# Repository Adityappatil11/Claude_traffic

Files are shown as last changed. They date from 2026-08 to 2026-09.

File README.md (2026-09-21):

# Claude Code Hardware Traffic Light Indicator 🚥

A physical status indicator with LED states and audio buzzer alerts for [Claude Code](https://docs.anthropic.com/claude/docs/claude-code) and CLI coding agents powered by an ESP8266 / NodeMCU.

---

## 🌟 Visual & Audio Signals

| State | LED Color | Buzzer Pattern | Trigger |
| :--- | :--- | :--- | :--- |
| **Prompt Dispatched / Action Needed** | 🟡 Yellow | 3 Short Beeps (120ms each) | `UserPromptSubmit`, `PermissionRequest`, `Notification` |
| **Tool Execution** | 🔵 Blue | Silent | `PreToolUse`, `PostToolUse` (Edit, Bash, Read) |
| **Prompt Completed** | ⚫ Off | 2 Short Beeps (120ms each) | `Stop`, `SessionEnd` |
| **Idle / Manual Off** | ⚫ Off | Silent | Manual `off` command |
| **Context Limit / Out of Tokens** | 🔴 Red | 1 Long Alarm (800ms) | Context window $\ge 95\%$ or `stop_reason == "max_tokens"` |

---

## 🛠️ Hardware Wiring

| Component | NodeMCU Pin | GPIO Pin | Notes |
| :--- | :--- | :--- | :--- |
| **🔴 Red LED** | `D1` | GPIO 5 | 220Ω–330Ω to Anode (+), Cathode to GND |
| **🟡 Yellow LED** | `D2` | GPIO 4 | 220Ω–330Ω to Anode (+), Cathode to GND |
| **🔵 Blue LED** | `D5` | GPIO 14 | 220Ω–330Ω to Anode (+), Cathode to GND |
| **🔔 Buzzer** | `D6` | GPIO 12 | Positive (+) to D6, Negative (-) to GND |

---

## 🚀 Quick Start

### 1. Prerequisites & Toolchain Setup

Install `arduino-cli`, `esptool`, and the ESP8266 board core:

```bash
# Install arduino-cli
curl -fsSL [https://raw.githubusercontent.com/arduino/arduino-cli/master/install.sh](https://raw.githubusercontent.com/arduino/arduino-cli/master/install.sh) | BINDIR=~/.local/bin sh
export PATH=$PATH:~/.local/bin

# Initialize config & add ESP8266 core
arduino-cli config init
arduino-cli config add board_manager.additional_urls [http://arduino.esp8266.com/stable/package_esp8266com_index.json](http://arduino.esp8266.com/stable/package_esp8266com_index.json)
arduino-cli core update-index
arduino-cli core install esp8266:esp8266

# Install esptool & serial tools
pip install esptool pyserial

```

---

### 2. Identify the Port & Fix Permissions

Plug your NodeMCU board into your computer and find the active serial port:

#### Linux

```bash
# Confirm that the NodeMCU is available as /dev/ttyUSB0
sudo ls -l /dev/ttyUSB* /dev/ttyACM* 2>/dev/null

# Give the current machine session access to the board
sudo chmod 666 /dev/ttyUSB0

# Or view kernel hardware detection logs
dmesg | grep -i tty
```

> **Important Linux Fixes:**
> 1. **Permission Denied:** The `chmod` command above is temporary and may need to be repeated after reconnecting or restarting the board. For permanent access, add your user to `dialout`, then log out and back in:
> ```bash
> sudo usermod -a -G dialout $USER
> ```
> 
> 
> 2. **Device Auto-Disconnecting (`brltty` Conflict):** If `/dev/ttyUSB0` disappears immediately after plugging in:
> ```bash
> sudo apt remove --purge -y brltty
> 
> ```
> 
> 
> 
> 

#### Windows (PowerShell)

```powershell
# List available COM ports
Get-CimInstance Win32_SerialPort | Select-Object DeviceID, Description

```

*(Look for `Silicon Labs CP210x` or `USB-SERIAL CH340` $\rightarrow$ e.g., `COM3`).*

---

### 3. Configure, Compile & Flash the Firmware

1. Open `firmware/firmware.ino` and enter the two 2.4 GHz Wi-Fi profiles:
```cpp
WifiCredential wifiCredentials[] = {
  {"Vishwa", "YOUR_PASSWORD", IPAddress(192, 168, 0, 200), IPAddress(192, 168, 0, 1)},
  {"Gramle_Jio", "YOUR_PASSWORD", IPAddress(192, 168, 31, 200), IPAddress(192, 168, 31, 1)}
};

```

The ESP8266 tries the profiles in order. It uses `192.168.0.200` on Vishwa and `192.168.31.200` on Gramle_Jio.

2. From the project directory, compile the binary:
```bash
arduino-cli compile --fqbn esp8266:esp8266:nodemcuv2 --output-dir ./build firmware/
```

3. Confirm the board is connected and make the serial port accessible:

```bash
sudo ls -l /dev/ttyUSB* /dev/ttyACM* 2>/dev/null
sudo chmod 666 /dev/ttyUSB0
```

4. Flash the ESP8266 using the settings verified with this board:

```bash
python3 -m esptool --chip esp8266 --port /dev/ttyUSB0 --baud 57600 --no-stub write-flash 0x0 ./build/firmware.ino.bin
```

A successful flash ends with `Verifying written data...` followed by `Hard resetting via RTS pin...`.

5. If esptool cannot connect automatically, put the board into **Bootloader Mode** and run the flash command again:

* Press and hold the physical **`FLASH`** (or `BOOT`) button.
* Tap the physical **`RST`** button once.
* Release the **`FLASH`** button.

#### Windows flashing

```bash
# Windows (replace COM3 with your port)
python -m esptool --port COM3 --baud 115200 --no-stub --before no-reset --after no-reset write-flash 0x0 ./build/firmware.ino.bin
```

---

### 4. Monitor Serial Output

1. **Press the `RST` button** on your NodeMCU once to start the firmware.
2. Open the serial monitor:
```bash
# Linux / macOS
python3 -m serial.tools.miniterm /dev/ttyUSB0 115200

# Windows
python -m serial.tools.miniterm COM3 115200

```

3. Watch the terminal for your Wi-Fi confirmation:
```text
WiFi Connected!
Connected SSID: Vishwa
NodeMCU Fixed IP Address: 192.168.0.200

```

4. Press `Ctrl + ]` to exit the monitor.

---

### 5. Configure the Light Sender and Hooks

`hw_light.py` sends every light command to both saved ESP8266 addresses. No per-PC IP edit is needed.

| Wi-Fi | ESP8266 address |
| :--- | :--- |
| Vishwa | `192.168.0.200` |
| Gramle_Jio | `192.168.31.200` |

The computer only needs to be connected to either Wi-Fi network.

#### Linux

```bash
chmod +x /path/to/Claude_traffic/hw_light.py

# Claude Code: only copies when no settings file exists
mkdir -p ~/.claude
test -e ~/.claude/settings.json || cp settings.json.example ~/.claude/settings.json

# Codex: only copies when no hooks file exists
mkdir -p ~/.codex
test -e ~/.codex/hooks.json || cp codex-hooks.json.example ~/.codex/hooks.json
```

Replace `/media/aditya/STUDY/projects/Claude_traffic` in the example JSON if your project is in a different folder. Use `.claude/settings.json` or `.codex/hooks.json` in a repository instead when hooks should only apply to that repository. Restart Claude Code or Codex after changing its settings.

#### Windows (PowerShell)

1. Install Python 3 and check that the launcher works:

```powershell
py -3 --version
```

2. Copy this project to a stable path, such as `C:\Users\YOUR_NAME\Claude_traffic`.

3. Replace every `YOUR_NAME` in [settings.windows.json.example](settings.windows.json.example), then merge it into:

```text
C:\Users\YOUR_NAME\.claude\settings.json
```

4. Replace every `YOUR_NAME` in [codex-hooks.windows.json.example](codex-hooks.windows.json.example), then copy it to:

```text
C:\Users\YOUR_NAME\.codex\hooks.json
```

Restart Claude Code or Codex after saving. Codex may ask you to trust the hook the first time it runs.

---

### 6. Manual Testing

These tests do not require Claude Code or Codex. They send the same UDP commands that the hooks send.

### Claude Desktop on Windows (experimental)

Claude Desktop does not expose Claude Code lifecycle hooks. The included log
watcher can infer activity from local Desktop logs, but log wording can change
between Claude releases.

```powershell
# Show the Claude Desktop logs detected on this PC
py -3 .\claude_desktop_watcher.py --discover

# First test without sending anything to the hardware. Send a Claude message
# while this is running and inspect the detected colour events/log wording.
py -3 .\claude_desktop_watcher.py --dry-run --verbose

# Run the traffic-light watcher
py -3 .\claude_desktop_watcher.py
```

The watcher checks both the classic `%APPDATA%\Claude\logs` location and the
Microsoft Store/MSIX package location. If automatic discovery misses the active
log, pass it explicitly with `--log-file "C:\path\to\claude.ai-web.log"`.

#### Linux

Run these from the project directory:

```bash
# Yellow: prompt / attention needed
python3 hw_light.py UserPromptSubmit

# Blue: tool running
python3 hw_light.py PreToolUse

# Red: interrupt / context warning
python3 hw_light.py Interrupt

# Complete: LEDs off with two short beeps
python3 hw_light.py Stop

# Guided sequence: Yellow -> Blue -> Off, plus manual colour selection
python3 simulate_claude.py
```

#### Windows (PowerShell)

Open PowerShell in the project directory:

```powershell
# Yellow: prompt / attention needed
py -3 .\hw_light.py UserPromptSubmit

# Blue: tool running
py -3 .\hw_light.py PreToolUse

# Red: interrupt / context warning
py -3 .\hw_light.py Interrupt

# Complete: LEDs off with two short beeps
py -3 .\hw_light.py Stop

# Guided sequence: Yellow -> Blue -> Off, plus manual colour selection
py -3 .\simulate_claude.py
```

If the light does not change, confirm the PC is connected to the same Wi-Fi as the board, then ping the active address:

```bash
# Linux: use 192.168.31.200 when connected to Gramle_Jio
ping -c 1 192.168.0.200
```

```powershell
# Windows: use 192.168.31.200 when connected to Gramle_Jio
ping 192.168.0.200
```

---

### 7. Claude Desktop Setup (Manual MCP Light Controls)

Claude Desktop does not provide Claude Code lifecycle hooks. Instead, this project includes a local MCP server that gives Claude Desktop tools to control the light on request:

| Tool | Action |
| :--- | :--- |
| `light_test` | Sends yellow as a quick connectivity test |
| `light_yellow` | Turns on yellow |
| `light_blue` | Turns on blue |
| `light_red` | Turns on red |
| `light_off` | Turns all LEDs off |
| `set_light` | Accepts `yellow`, `blue`, `red`, or `off` |

You do **not** need an `.mcpb` file for this manual setup. The `.mcpb` file is only needed when using Claude Desktop's **Settings -> Extensions -> Advanced settings -> Install Extension...** flow.

The MCP server sends every command to both ESP8266 addresses:

```text
192.168.0.200
192.168.31.200
```

That means the same Claude Desktop config can work whether the computer is connected to the Vishwa Wi-Fi or the Gramle_Jio Wi-Fi.

#### Windows

1. Open PowerShell and go to the project directory:

```powershell
cd C:\Users\graml\Downloads\Claude_traffic
```

If you keep the project somewhere else, use that folder instead.

2. Install the MCP dependency:

```powershell
py -3 -m pip install -r .\claude_desktop\requirements.txt
```

3. Confirm the MCP server can start:

```powershell
py -3 .\claude_desktop\traffic_light_mcp.py
```

The command may wait silently because Claude Desktop normally talks to it over standard input/output. Press `Ctrl+C` to stop it after confirming there is no startup error.

4. Open the Claude Desktop config file:

```powershell
notepad "$env:APPDATA\Claude\claude_desktop_config.json"
```

If the file does not exist, create it.

5. Add or merge this config. If the file already has other MCP servers, only add the `esp8266-traffic-light` entry inside `mcpServers`.

```json
{
  "mcpServers": {
    "esp8266-traffic-light": {
      "command": "py",
      "args": [
        "-3",
        "C:\\Users\\graml\\Downloads\\Claude_traffic\\claude_desktop\\traffic_light_mcp.py"
      ],
      "env": {
        "ESP8266_LIGHT_IPS": "192.168.0.200,192.168.31.200"
      }
    }
  }
}
```

6. Fully quit Claude Desktop and reopen it.

7. Start a chat and ask:

```text
Use the esp8266 traffic light tool and run light_test.
```

The yellow light should turn on. Claude Desktop may ask you to approve the tool the first time.

#### macOS

1. Copy the project to your Mac and install the MCP dependency:

```bash
cd /Users/YOUR_NAME/Claude_traffic
python3 -m pip install -r claude_desktop/requirements.txt
```

2. Open or create Claude Desktop's config file:

```bash
open "$HOME/Library/Application Support/Claude/claude_desktop_config.json"
```

If `open` does not create the file, make the folder and file manually:

```bash
mkdir -p "$HOME/Library/Application Support/Claude"
touch "$HOME/Library/Application Support/Claude/claude_desktop_config.json"
```

3. Add or merge this config. Replace `YOUR_NAME` with your macOS user name:

```json
{
  "mcpServers": {
    "esp8266-traffic-light": {
      "command": "python3",
      "args": [
        "/Users/YOUR_NAME/Claude_traffic/claude_desktop/traffic_light_mcp.py"
      ],
      "env": {
        "ESP8266_LIGHT_IPS": "192.168.0.200,192.168.31.200"
      }
    }
  }
}
```

4. Fully quit Claude Desktop and reopen it.

5. In a chat, ask:

```text
Use the esp8266 traffic light tool and run light_test.
```

#### Linux Testing

Claude Desktop support on Linux depends on the installation channel/version. You can still test the MCP server itself from this repository:

```bash
cd /media/aditya/STUDY/projects/Claude_traffic
python3 -m pip install -r claude_desktop/requirements.txt
python3 claude_desktop/traffic_light_mcp.py
```

Press `Ctrl+C` after confirming the server starts.

Use this config shape if your Claude Desktop build exposes a local MCP config file:

```json
{
  "mcpServers": {
    "esp8266-traffic-light": {
      "command": "python3",
      "args": [
        "/media/aditya/STUDY/projects/Claude_traffic/claude_desktop/traffic_light_mcp.py"
      ],
      "env": {
        "ESP8266_LIGHT_IPS": "192.168.0.200,192.168.31.200"
      }
    }
  }
}
```

The ready-made examples are also included here:

| Platform | Example file |
| :--- | :--- |
| macOS | [claude_desktop_config.macos.example.json](claude_desktop/claude_desktop_config.macos.example.json) |
| Windows | [claude_desktop_config.windows.example.json](claude_desktop/claude_desktop_config.windows.example.json) |

#### Troubleshooting

If Claude Desktop does not show the tool, check these first:

1. Restart Claude Desktop after changing `claude_desktop_config.json`.
2. Confirm Python works from the same terminal: `py -3 --version` on Windows or `python3 --version` on macOS/Linux.
3. Confirm the MCP package is installed: `py -3 -m pip show mcp` or `python3 -m pip show mcp`.
4. Confirm the path in `args` points to the real `traffic_light_mcp.py` location.
5. Confirm the ESP8266 is on either `192.168.0.200` or `192.168.31.200`.

For automatic Claude Desktop activity detection on Windows, you can also try the experimental log watcher:

```powershell
py -3 .\claude_desktop_watcher.py --discover
py -3 .\claude_desktop_watcher.py --dry-run --verbose
py -3 .\claude_desktop_watcher.py
```

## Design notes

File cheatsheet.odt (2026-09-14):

Here is a complete, structured breakdown of every issue we encountered, why it happened, and the exact Linux CLI commands that solved it.

### Phase 1: Fixing Linux Hardware & Driver Conflicts

#### 1. The brltty Conflict (Device Disconnecting Immediately)

- What happened: Ubuntu and Debian install brltty (Braille Display Daemon) by default. When a CH340 USB-to-Serial converter is plugged in, brltty misidentifies it as a Braille teletype and claims the USB interface, forcibly disconnecting /dev/ttyUSB0 half a second later.
- The fix:
  Bash
  # Completely remove the conflicting braille daemon
  sudo apt remove --purge -y brltty
  sudo systemctl stop brltty-udev.service 2>/dev/null
  sudo systemctl mask brltty-udev.service 2>/dev/null

#### 2. Serial Port Permissions (Permission denied / dialout)

- What happened: Linux restricts raw access to hardware serial ports (/dev/ttyUSB*, /dev/ttyACM*) to the root user and the dialout group. Standard user accounts cannot write to serial ports without being in this group.
- The fix:
  Bash
  # Add your current user to the dialout group
  sudo usermod -a -G dialout $USER
  # Make the active device read/write accessible to all local users
  sudo chmod 666 /dev/ttyUSB0

### Phase 2: Headless Toolchain Setup (arduino-cli)

Instead of relying on heavy desktop IDEs, arduino-cli allows compiling and managing board cores completely from the terminal.

Bash

# 1. Download and install arduino-cli binary to your local user bin

curl -fsSL https://raw.githubusercontent.com/arduino/arduino-cli/master/install.sh | BINDIR=~/.local/bin sh

export PATH=$PATH:~/.local/bin

# 2. Register ESP8266 board manager repository index

arduino-cli config init

arduino-cli config add board_manager.additional_urls http://arduino.esp8266.com/stable/package_esp8266com_index.json

# 3. Update the package index and install the core toolchain (xtensa-lx106 compiler, SDK, libraries)

arduino-cli core update-index

arduino-cli core install esp8266:esp8266

### Phase 3: Headless Compilation to Raw Binary

Compiling with --output-dir produces a self-contained .bin firmware file that can be flashed using any low-level tool:

Bash

# Compiles the sketch targeting NodeMCU 1.0 (ESP-12E) and outputs to ./build/

arduino-cli compile --fqbn esp8266:esp8266:nodemcuv2 --output-dir ./build firmware/

- --fqbn stands for Fully Qualified Board Name (esp8266:esp8266:nodemcuv2).
- Generates ./build/firmware.ino.bin.

### Phase 4: Solving the [Errno 5] / [Errno 71] Flashing Crashes

#### Why esptool.py Failed Initially:

1. The Stub Mismatch: By default, esptool uploads a small RAM program (a "stub flasher") into the ESP8266's memory to flash at higher baud rates. On cheap CH340 clones running under the Linux kernel's ch341 driver, the USB packet framing breaks during this stub handoff, causing [Errno 71] Protocol error.
2. DTR/RTS Line Crash: The automatic reset circuitry pulses the DTR and RTS lines. On some USB controllers, this line transition resets the USB endpoint mid-transfer, dropping the port and causing [Errno 5] Input/output error.

#### The Solution: ROM Bootloader + Manual Sync

1. Manual Bootloader Entry: Holding FLASH, tapping RST, and releasing FLASH puts the ESP8266 chip directly into its internal ROM bootloader state in hardware.
2. Direct Flashing Command:
  Bash
  python3 -m esptool --port /dev/ttyUSB0 --baud 115200 --no-stub --before no-reset --after no-reset write-flash 0x0 ./build/firmware.ino.bin
  - --no-stub: Bypasses the RAM flasher stub completely and speaks directly to the built-in ESP8266 ROM flasher.
  - --before no-reset: Tells esptool NOT to send DTR/RTS serial pulses before flashing (preventing USB controller resets).
  - --after no-reset: Prevents esptool from sending a hardware line reset after writing (preventing pySerial I/O crashes).
  - 0x0: Flashes the binary directly to the primary boot address of the ESP8266 SPI flash memory.

### Phase 5: Monitoring Output

Bash

# Built-in lightweight terminal monitor via pySerial

python3 -m serial.tools.miniterm /dev/ttyUSB0 115200

- Quit: Ctrl + ]

### Quick Cheat Sheet for Future ESP8266 Projects

Bash

# 1. Compile sketch

arduino-cli compile --fqbn esp8266:esp8266:nodemcuv2 --output-dir ./build sketch_folder/

# 2. Put board in bootloader mode:

# Hold FLASH -> Tap RST -> Release FLASH

# 3. Flash reliably

python3 -m esptool --port /dev/ttyUSB0 --baud 115200 --no-stub --before no-reset --after no-reset write-flash 0x0 ./build/*.bin

# 4. Press RST once on the board, then open monitor

python3 -m serial.tools.miniterm /dev/ttyUSB0 115200

Now, update ESP32_IP = "192.168.0.5" in hw_light.py and run python3 simulate_claude.py.

### Compile and Flash via Linux CLI

1. Recompile the firmware:
  Bash
  cd /media/aditya/STUDY/projects/Claude_traffic/
  arduino-cli compile --fqbn esp8266:esp8266:nodemcuv2 --output-dir ./build firmware/
2. Put board in bootloader mode:
  - Press and hold FLASH $\rightarrow$ Tap RST $\rightarrow$ Release FLASH.
3. Upload to board:
  Bash
  python3 -m esptool --port /dev/ttyUSB0 --baud 115200 --no-stub --before no-reset --after no-reset write-flash 0x0 ./build/firmware.ino.bin
4. Boot the board:
  - Press RST on the NodeMCU once to run the new firmware.

[Errno 2] No such file or directory: '/dev/ttyUSB0' means the board either re-enumerated under a different device name (such as /dev/ttyUSB1) or the USB connection was momentarily dropped when wiring the buzzer.

### Step 1: Check the Active Port Name

Run:

ls -l /dev/ttyUSB* /dev/ttyACM* 2>/dev/null

Bash

ls -l /dev/ttyUSB* /dev/ttyACM* 2>/dev/null

- If it shows /dev/ttyUSB1, use /dev/ttyUSB1 in your command.
- If nothing is returned, unplug the USB cable, plug it back in, and run the command again to confirm which port appears.

### Step 2: Grant Permissions

sudo chmod 666 /dev/ttyUSB* 2>/dev/null || sudo chmod 666 /dev/ttyACM* 2>/dev/null

sudo chmod 666 /dev/ttyUSB* 2>/dev/null || sudo chmod 666 /dev/ttyACM* 2>/dev/null

### Step 3: Enter Bootloader Mode

1. Press and hold the FLASH button on your NodeMCU.
2. While holding FLASH, press and release the RST button once.
3. Release the FLASH button.

### Step 4: Flash Firmware

Run the flash command (replacing /dev/ttyUSB0 with the active port if different):

Bash

python3 -m esptool --port /dev/ttyUSB0 --baud 115200 --no-stub --before no-reset --after no-reset write-flash 0x0 ./build/firmware.ino.bin

### Step 5: Boot the NodeMCU

1. Press the RST button on the board once.
2. You will hear the startup beep sequence and see the LEDs run through their self-test.

arduino-cli upload -p /dev/ttyUSB0 --fqbn esp8266:esp8266:nodemcuv2 firmware/

[Errno 5] Input/output error: '/dev/ttyUSB0' occurs when the Linux kernel disconnects the USB-to-UART bridge (often due to brltty or ModemManager interfering, or insufficient USB current during flashing).

### Step 1: Remove the Known brltty Conflict (Most Common on Ubuntu/Debian)

Ubuntu automatically installs a braille device service (brltty) that seizes CH340 and CP210x USB-serial adapters and forces an I/O reset whenever they are opened:

Bash

sudo apt remove --purge -y brltty

sudo systemctl stop ModemManager 2>/dev/null

### Step 2: Clear Port Locks & Check Kernel Status

1. Unplug and re-plug the NodeMCU's USB cable into a direct motherboard USB port (avoid unpowered hubs).
2. Check the kernel logs to see what happened to the device:
  Bash
  dmesg | tail -n 25
  (Confirm that the CH340 or CP210x attached cleanly as ttyUSB0).
3. Kill any residual background processes:
  Bash
  sudo fuser -k /dev/ttyUSB0 2>/dev/null
  sudo chmod 666 /dev/ttyUSB0

### Step 3: Put NodeMCU into Manual Bootloader Mode

1. Press and hold the physical FLASH button on your NodeMCU.
2. While holding FLASH, press and release the RST button once.
3. Release the FLASH button[cite: 1].

### Step 4: Flash at a Lower Baud Rate

Some USB cables or hubs cannot sustain 115200 or 921600 baud without I/O drops. Flash with arduino-cli using explicit upload properties, or use esptool with a conservative baud rate:

Bash

# Upload via arduino-cli with upload speed explicitly set:

arduino-cli upload -p /dev/ttyUSB0 --fqbn esp8266:esp8266:nodemcuv2 --upload-property upload.speed=115200 firmware/

Or via direct esptool:

Bash

python3 -m esptool --chip esp8266 --port /dev/ttyUSB0 --baud 115200 write-flash 0x0 ./build/firmware.ino.bin

The auto-reset circuit on your CH340 board is not pulling GPIO0 low automatically, so the chip is not entering flash mode.

Do the manual hardware sync while the command is actively running:

### Step 1: Manual Bootloader Sequence (During Handshake)

1. Press and hold the physical FLASH button on your NodeMCU board.
2. While holding FLASH, press and release the physical RST button once.
3. Keep holding FLASH, then run the flash command in your terminal:
  Bash
  python3 -m esptool --chip esp8266 --port /dev/ttyUSB0 --baud 115200 write_flash 0x0 ./build/firmware.ino.bin
4. As soon as you see Connecting......., release the FLASH button.

### Step 2: Try Slower Baud Rate (If Still Timing Out)

CH340 chips occasionally drop packets during initial sync at 115200 baud. Lowering the baud rate resolves this:

Bash

python3 -m esptool --chip esp8266 --port /dev/ttyUSB0 --baud 57600 write_flash 0x0 ./build/firmware.ino.bin

(Repeat the FLASH + RST button hold while executing this command).

### Step 3: Check Wiring Interference

If you have anything connected to the D3 (GPIO0), TX (GPIO1), or RX (GPIO3) pins, disconnect those jumper wires temporarily, as they directly block the bootloader and UART serial communication.

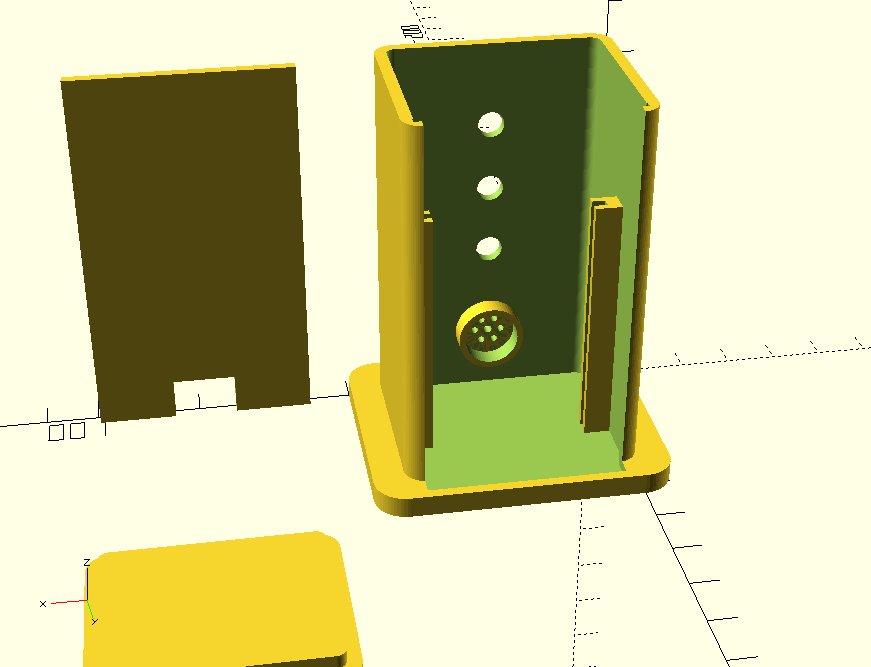
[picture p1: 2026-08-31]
design/traffic_light.png

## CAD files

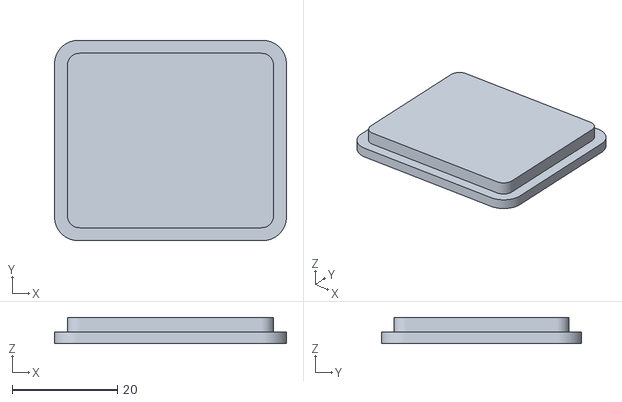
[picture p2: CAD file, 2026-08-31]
design/lid.stl
44.0 x 38.0 x 5.00

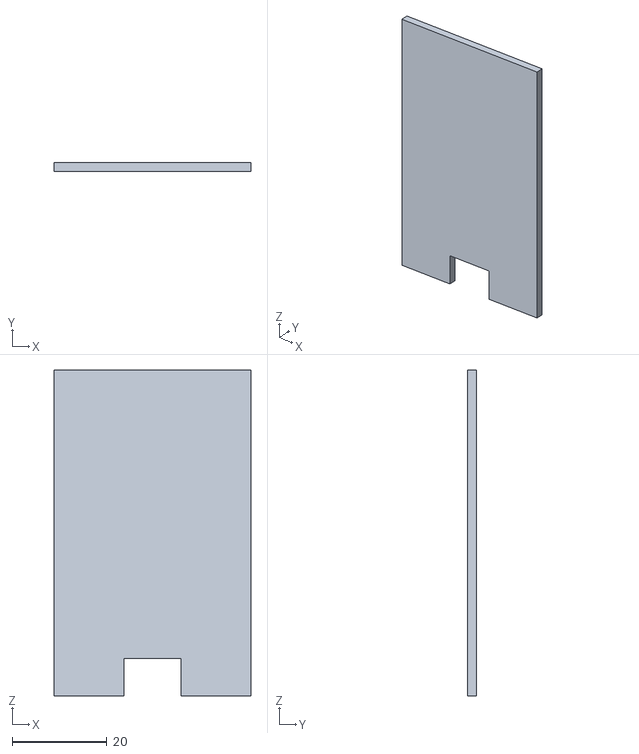
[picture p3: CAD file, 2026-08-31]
design/access_door.stl
41.5 x 2.00 x 68.7

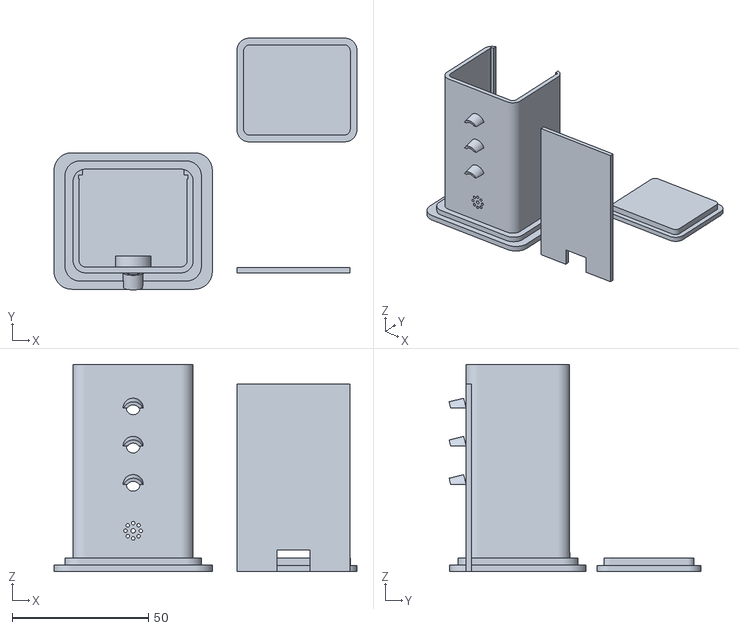
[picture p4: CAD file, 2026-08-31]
design/traffic_light.stl
111.0 x 92.2 x 76.0

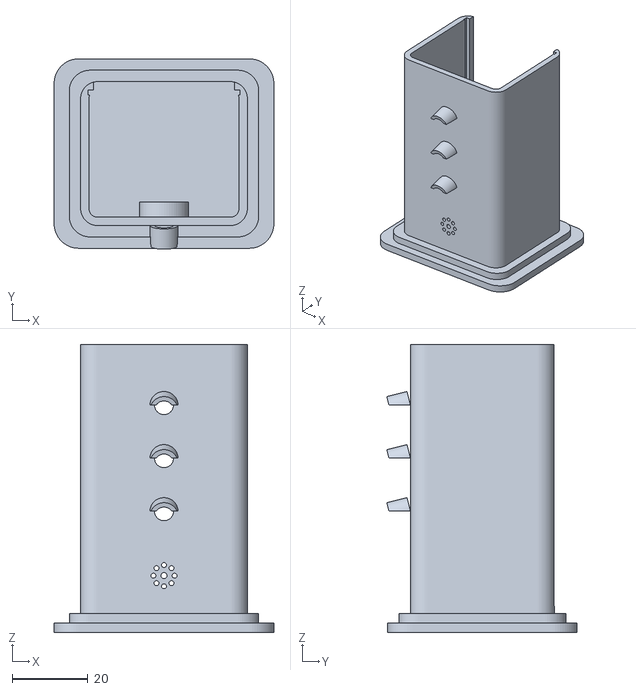
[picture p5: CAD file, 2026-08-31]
design/traffic_light_chassis.stl
58.0 x 50.2 x 76.0

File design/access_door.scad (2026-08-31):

// =================================================================
// PART 2: Slide-in Rear Door Panel
// Units: Millimeters (mm)
// =================================================================

body_w = 44.0;
body_h = 76.0;
wall   = 2.2;
floor_t= 2.0;
base_h1 = 2.5;
base_h2 = 2.5;

usb_w = 12.0;
usb_h = 8.0;

module slide_in_back_door() {
    door_w = body_w - 2 * wall + 2 * 1.2 - 0.5;
    door_h = body_h - (floor_t + base_h1 + base_h2) - 0.3;

    difference() {
        union() {
            cube([door_w, 2.0, door_h]);
            cube([0.9, 1.1, door_h]);
            translate([door_w - 0.9, 0, 0])
                cube([0.9, 1.1, door_h]);
        }

        translate([(door_w / 2) - (usb_w / 2), -1, -0.1])
            cube([usb_w, 6.0, usb_h]);

        translate([(door_w / 2) - 7.5, 1.2, door_h - 6.0])
            cube([15.0, 1.5, 2.5]);
    }
}

// Render Door flat for printing
slide_in_back_door();

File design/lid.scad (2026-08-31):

// =================================================================
// PART 3: Top Snap-On Enclosure Lid
// Units: Millimeters (mm)
// =================================================================

$fn = 60;

body_w   = 44.0;
body_d   = 38.0;
wall     = 2.2;
corner_r = 4.5;

module rounded_box(w, d, h, r) {
    hull() {
        translate([r, r, 0]) cylinder(r=r, h=h);
        translate([w - r, r, 0]) cylinder(r=r, h=h);
        translate([r, d - r, 0]) cylinder(r=r, h=h);
        translate([w - r, d - r, 0]) cylinder(r=r, h=h);
    }
}

module top_enclosure_lid() {
    union() {
        rounded_box(body_w, body_d, 2.2, corner_r);

        translate([wall + 0.25, wall + 0.25, 2.2])
            rounded_box(
                body_w - 2*(wall + 0.25),
                body_d - 2*(wall + 0.25),
                2.8,
                max(0.5, corner_r - wall)
            );
    }
}

// Render Lid
top_enclosure_lid();

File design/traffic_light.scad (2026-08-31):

// =================================================================
// Premium Desktop Traffic Light Tower (Open-Chamber Edition)
// No MCU rails — maximum internal space for easy wire bundling
// Units: Millimeters (mm)
// =================================================================

$fn = 60; // Smooth curve resolution

// --- Main Enclosure Dimensions ---
body_w = 44.0;       // Outer Width (X)
body_d = 38.0;       // Outer Depth (Y)
body_h = 76.0;       // Tower Height (Z)
wall   = 2.2;        // Wall thickness
floor_t= 2.0;        // Base floor thickness
corner_r = 4.5;      // Smooth outer corner radius

// --- Tiered Anti-Tip Pedestal Base ---
base_w1 = 58.0; base_d1 = 50.0; base_h1 = 2.5; // Bottom tier
base_w2 = 50.0; base_d2 = 44.0; base_h2 = 2.5; // Step tier

// --- Component Specifications ---
led_dia = 5.0;                  // 5mm LED press fit
led_z   = [60, 46, 32];         // Red (60), Yellow (46), Blue (32)
visor_proj = 5.5;               // Sun hood projection length
visor_wall = 1.2;

// Buzzer Retainer Ring (Bottom Face)
buzzer_od = 10.5;               // Sized for 10.2mm buzzer
buzzer_wall = 1.2;
buzzer_depth = 4.0;
buzzer_z = 15.0;                // Centered below all 3 LEDs

// Rear Micro-USB Cutout
usb_w = 12.0;
usb_h = 8.0;

// --- Helper: Rounded Solid Box ---
module rounded_box(w, d, h, r) {
    hull() {
        translate([r, r, 0]) cylinder(r=r, h=h);
        translate([w - r, r, 0]) cylinder(r=r, h=h);
        translate([r, d - r, 0]) cylinder(r=r, h=h);
        translate([w - r, d - r, 0]) cylinder(r=r, h=h);
    }
}

// --- MODULE: Curved Sun Visor Hood ---
module traffic_visor() {
    difference() {
        // Outer hood cylinder angled 14 degrees downward
        rotate([90, 0, 0])
            rotate([14, 0, 0])
                cylinder(d = led_dia + (2 * visor_wall), h = visor_proj, center = false);

        // Hollow interior for LED lens
        rotate([90, 0, 0])
            rotate([14, 0, 0])
                translate([0, 0, -1])
                    cylinder(d = led_dia, h = visor_proj + 3, center = false);

        // Trim bottom half
        translate([-(led_dia + 6)/2, -(visor_proj + 4), -(led_dia + 6)])
            cube([led_dia + 6, visor_proj + 6, led_dia + 6]);
    }
}

// --- MODULE 1: Main Traffic Light Chassis ---
module traffic_light_chassis() {
    union() {
        difference() {
            union() {
                // Tiered Pedestal Base
                translate([-(base_w1 - body_w)/2, -(base_d1 - body_d)/2, 0])
                    rounded_box(base_w1, base_d1, base_h1, corner_r + 2);

                translate([-(base_w2 - body_w)/2, -(base_d2 - body_d)/2, base_h1])
                    rounded_box(base_w2, base_d2, base_h2, corner_r + 1);

                // Main Tower
                translate([0, 0, base_h1 + base_h2])
                    rounded_box(body_w, body_d, body_h - (base_h1 + base_h2), corner_r);
            }

            // Wide, Open Hollow Internal Cavity (Clean space for all components)
            translate([wall, wall, floor_t + base_h1 + base_h2])
                rounded_box(body_w - (2 * wall), body_d - (2 * wall), body_h + 10, max(0.5, corner_r - wall));

            // Rear Opening (Full vertical back access)
            translate([wall + 1.2, body_d - wall - 2, floor_t + base_h1 + base_h2])
                cube([body_w - 2*(wall + 1.2), wall + 5, body_h]);

            // Rear Wall Door Rails
            translate([wall - 0.2, body_d - wall - 1.4, floor_t + base_h1 + base_h2])
                cube([1.6, 1.4, body_h]);

            translate([body_w - wall - 1.4, body_d - wall - 1.4, floor_t + base_h1 + base_h2])
                cube([1.6, 1.4, body_h]);

            // Front Face: 3x LED Lens Holes
            for (z = led_z) {
                translate([body_w / 2, wall + 2, z])
                    rotate([90, 0, 0])
                    cylinder(d = led_dia, h = wall + 5);
            }

            // Front Face: Acoustic Buzzer Rosette
            for (ang = [0:45:315]) {
                translate([(body_w / 2) + 2.8 * cos(ang), wall + 2, buzzer_z + 2.8 * sin(ang)])
                    rotate([90, 0, 0])
                    cylinder(d = 1.3, h = wall + 5);
            }
            translate([body_w / 2, wall + 2, buzzer_z])
                rotate([90, 0, 0])
                cylinder(d = 1.6, h = wall + 5);
        }

        // Add 3x Outward Traffic Visors
        for (z = led_z) {
            translate([body_w / 2, 0, z])
                traffic_visor();
        }

        // Internal Buzzer Retaining Cup (Holds buzzer firmly in place)
        translate([body_w / 2, wall, buzzer_z])
            rotate([-90, 0, 0])
                difference() {
                    cylinder(d = buzzer_od + (2 * buzzer_wall), h = buzzer_depth);
                    translate([0, 0, -0.5])
                        cylinder(d = buzzer_od, h = buzzer_depth + 1.0);
                }
    }
}

// --- MODULE 2: Slide-in Rear Access Door ---
module slide_in_back_door() {
    door_w = body_w - 2 * wall + 2 * 1.2 - 0.5;
    door_h = body_h - (floor_t + base_h1 + base_h2) - 0.3;

    difference() {
        union() {
            cube([door_w, 2.0, door_h]);
            cube([0.9, 1.1, door_h]);
            translate([door_w - 0.9, 0, 0])
                cube([0.9, 1.1, door_h]);
        }

        // Micro-USB Cutout at bottom
        translate([(door_w / 2) - (usb_w / 2), -1, -0.1])
            cube([usb_w, 6.0, usb_h]);

        // Top finger notch for easy opening
        translate([(door_w / 2) - 7.5, 1.2, door_h - 6.0])
            cube([15.0, 1.5, 2.5]);
    }
}

// --- MODULE 3: Top Snap-On Lid ---
module top_enclosure_lid() {
    union() {
        rounded_box(body_w, body_d, 2.2, corner_r);

        translate([wall + 0.25, wall + 0.25, 2.2])
            rounded_box(
                body_w - 2*(wall + 0.25),
                body_d - 2*(wall + 0.25),
                2.8,
                max(0.5, corner_r - wall)
            );
    }
}

// =================================================================
// Render Scene
// =================================================================
traffic_light_chassis();

// Rear Door
translate([body_w + 16, 0, 0])
    slide_in_back_door();

// Removable Top Lid
translate([body_w + 16, body_d + 10, 0])
    top_enclosure_lid();

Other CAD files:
design/traffic_light_chassis.scad

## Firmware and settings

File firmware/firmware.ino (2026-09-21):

#include <ESP8266WiFi.h>
#include <WiFiUdp.h>

// Wi-Fi Credentials (2.4 GHz only)
struct WifiCredential {
  const char* ssid;
  const char* password;
  IPAddress localIP;
  IPAddress gateway;
};

WifiCredential wifiCredentials[] = {
  {"Vishwa", "vishwa@21062002", IPAddress(192, 168, 0, 200), IPAddress(192, 168, 0, 1)},
  {"Gramle_Jio", "Appu@123", IPAddress(192, 168, 31, 200), IPAddress(192, 168, 31, 1)}
};

const int wifiCredentialCount = sizeof(wifiCredentials) / sizeof(wifiCredentials[0]);
const unsigned long wifiConnectTimeoutMs = 15000;

// Shared network settings
IPAddress subnet(255, 255, 255, 0);     // Subnet mask
IPAddress primaryDNS(8, 8, 8, 8);       // Optional DNS
IPAddress secondaryDNS(8, 8, 4, 4);

WiFiUDP udp;
const unsigned int localUdpPort = 4210;
char incomingPacket[255];

// NodeMCU Pin Mapping
#define PIN_RED    D1
#define PIN_YELLOW D2
#define PIN_BLUE   D5
#define PIN_BUZZER D6

enum State { IDLE, WAITING, RUNNING, COMPLETE, OUT_OF_TOKENS };
State currentState = IDLE;

void setLEDs(bool red, bool yellow, bool blue) {
  digitalWrite(PIN_RED, red ? HIGH : LOW);
  digitalWrite(PIN_YELLOW, yellow ? HIGH : LOW);
  digitalWrite(PIN_BLUE, blue ? HIGH : LOW);
}

// Helper tone functions (works for both active and passive buzzers)
void shortBeep() {
  for(int i=0;i<3;i++)
  {
    digitalWrite(PIN_BUZZER, HIGH);
    delay(120);
    digitalWrite(PIN_BUZZER, LOW);
    if(i<2)
    {
      delay(100);
    }
  }
}

void longBeep() {
  digitalWrite(PIN_BUZZER, HIGH);
  delay(800);
  digitalWrite(PIN_BUZZER, LOW);
}

void completionBeep() {
  for (int i = 0; i < 2; i++) {
    digitalWrite(PIN_BUZZER, HIGH);
    delay(120);
    digitalWrite(PIN_BUZZER, LOW);
    if (i == 0) {
      delay(100);
    }
  }
}

void updateLED() {
  switch (currentState) {
    case WAITING:
      setLEDs(false, true, false);   // Yellow
      shortBeep();                   // Short Beep for prompt dispatched
      break;

    case RUNNING:
      setLEDs(false, false, true);   // Blue
      break;
    case OUT_OF_TOKENS:
      setLEDs(true, false, false);   // Red
      longBeep();                    // Long Warning Beep
      break;

    case COMPLETE:
      setLEDs(false, false, false);  // Work finished: LEDs off
      completionBeep();              // Two short completion beeps
      currentState = IDLE;
      break;

    case IDLE:
    default:
      setLEDs(false, false, false);  // Off
      break;
  }
}

bool connectToWiFi() {
  WiFi.mode(WIFI_STA);

  for (int i = 0; i < wifiCredentialCount; i++) {
    Serial.print("\nConnecting to Wi-Fi: ");
    Serial.println(wifiCredentials[i].ssid);

    WiFi.disconnect();
    delay(200);

    // Configure this Wi-Fi's Static IP before connecting
    if (!WiFi.config(wifiCredentials[i].localIP, wifiCredentials[i].gateway, subnet, primaryDNS, secondaryDNS)) {
      Serial.println("Failed to configure Static IP");
    }

    WiFi.begin(wifiCredentials[i].ssid, wifiCredentials[i].password);

    unsigned long startedAt = millis();
    while (WiFi.status() != WL_CONNECTED && millis() - startedAt < wifiConnectTimeoutMs) {
      setLEDs(false, true, false); delay(200);
      setLEDs(false, false, false); delay(200);
      Serial.print(".");
    }

    if (WiFi.status() == WL_CONNECTED) {
      Serial.println("\nWiFi Connected!");
      Serial.print("Connected SSID: ");
      Serial.println(wifiCredentials[i].ssid);
      return true;
    }

    Serial.println("\nWiFi not connected, trying next saved network...");
  }

  return false;
}

void setup() {
  Serial.begin(115200);

  pinMode(PIN_RED, OUTPUT);
  pinMode(PIN_YELLOW, OUTPUT);
  pinMode(PIN_BLUE, OUTPUT);
  pinMode(PIN_BUZZER, OUTPUT);
  digitalWrite(PIN_BUZZER, LOW);

  // Self-test LED + Audio check
  setLEDs(true, false, false); delay(150);
  setLEDs(false, true, false); delay(150);
  setLEDs(false, false, true); delay(150);
  setLEDs(false, false, false);
  shortBeep();

  while (!connectToWiFi()) {
    Serial.println("No saved Wi-Fi connected. Retrying all networks in 5 seconds...");
    setLEDs(true, true, false);
    delay(5000);
  }

  Serial.print("NodeMCU Fixed IP Address: ");
  Serial.println(WiFi.localIP());

  // Two quick blinks and double beep to confirm connection
  for (int i = 0; i < 2; i++) {
    setLEDs(false, false, true);
    digitalWrite(PIN_BUZZER, HIGH);
    delay(100);
    setLEDs(false, false, false);
    digitalWrite(PIN_BUZZER, LOW);
    delay(100);
  }

  udp.begin(localUdpPort);
  updateLED();
}

void loop() {
  int packetSize = udp.parsePacket();
  if (packetSize) {
    int len = udp.read(incomingPacket, 255);
    if (len > 0) {
      incomingPacket[len] = '\0';
      char cmd = incomingPacket[0];

      switch (cmd) {
        case 'Y': currentState = WAITING; break;
        case 'B': currentState = RUNNING; break;
        case 'R': currentState = OUT_OF_TOKENS; break;
        case 'C': currentState = COMPLETE; break;
        case 'O': currentState = IDLE; break;
        default: break;
      }
      updateLED();
    }
  }
}
